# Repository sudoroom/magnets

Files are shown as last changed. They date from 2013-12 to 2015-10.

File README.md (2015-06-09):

# Sudo Magnets

These are experiments in 3D-printing fridge magnets for our hackerspace. Check it out:

* [Hack The Planet](https://github.com/sudoroom/magnets/blob/master/hack-the-planet/world.stl "'Hack The Planet' magnet")
* [Mesh The Planet](https://github.com/sudoroom/magnets/blob/master/hack-the-planet/mesh.stl "'Mesh The Planet' magnet")
* [Sudo](https://github.com/sudoroom/magnets/blob/master/sudo/sudo.stl "'Sudo' magnet")
* [Heart](https://github.com/sudoroom/magnets/blob/master/heart/heart.stl "heart magnet")
* [Double Union](https://github.com/sudoroom/magnets/blob/master/double-union/du.stl "'Double Union' magnet")
* [Anti-Surveillance](https://github.com/sudoroom/magnets/blob/master/fuck-surveillance/cube.stl "'Fuck Surveillance' magnet")
* [ABOLISH](https://github.com/sudoroom/magnets/blob/master/abolish/abolish.stl "'ABOLISH' magnet")
* [Transgender Symbol](https://github.com/sudoroom/magnets/blob/master/trans/trans.stl "'trans symbol' magnet")

## Why?

Fridge magnets are useful objects, great conversation pieces, and good advertising since people look at them every day!

## How do you print magnets??

The model has a hole for [one of these](http://www.amazon.com/gp/product/B00C786XTU/ "Is there a non-Amazon link for this?"). The printer pauses while you insert it by hand. It also moves the bed, which hopefully will make a loud distinctive noise to alert you.

## How do I make one?

Almost everything is in the `compile.sh` scripts:
* openscad command to compile an STL
* slic3r command with the exact options we use
* awk command to insert the gcode pause

Right now the scripts also do non-portable stuff like edit my PATH and fix the tempurature for our particular plastic. Sorry, I'll fix it eventually.

## What about text and images?

The world map is from Wikipedia. I prepared images and text in the Inkscape GUI. Someday I'd like to script this with Python and have entirely deterministic magnets.

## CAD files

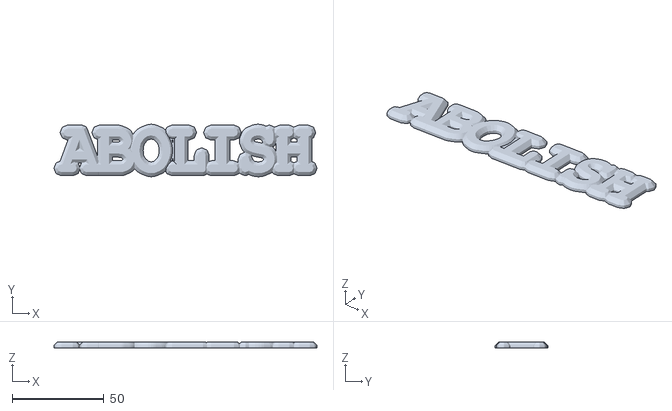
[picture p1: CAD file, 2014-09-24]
abolish/abolish-taz.stl
143.0 x 28.6 x 3.42

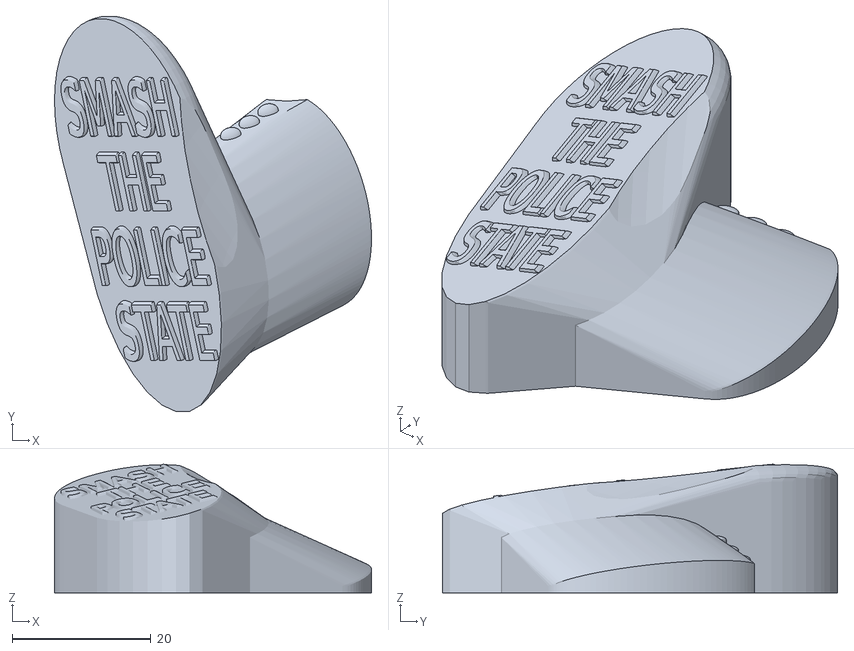
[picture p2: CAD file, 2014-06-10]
boot/boot.stl
45.7 x 57.0 x 18.6

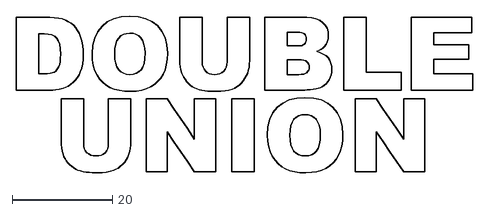
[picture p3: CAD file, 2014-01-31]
double-union/text.dxf
91.3 x 31.3

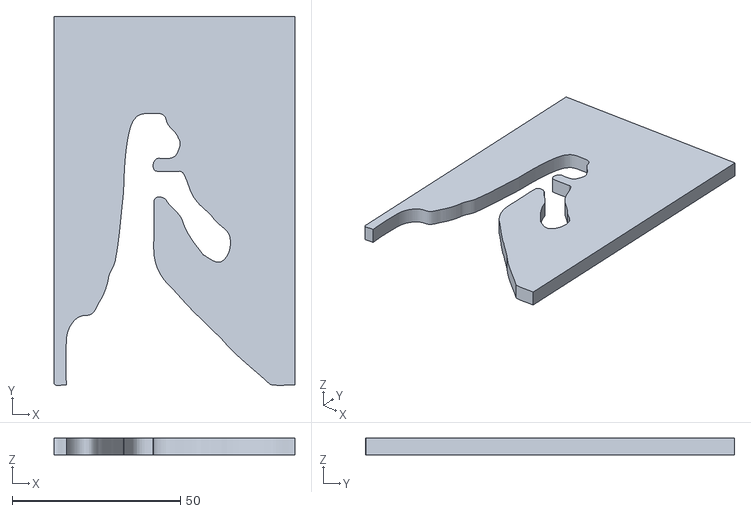
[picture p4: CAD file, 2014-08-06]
duck/duck.stl
71.6 x 109.6 x 5.00

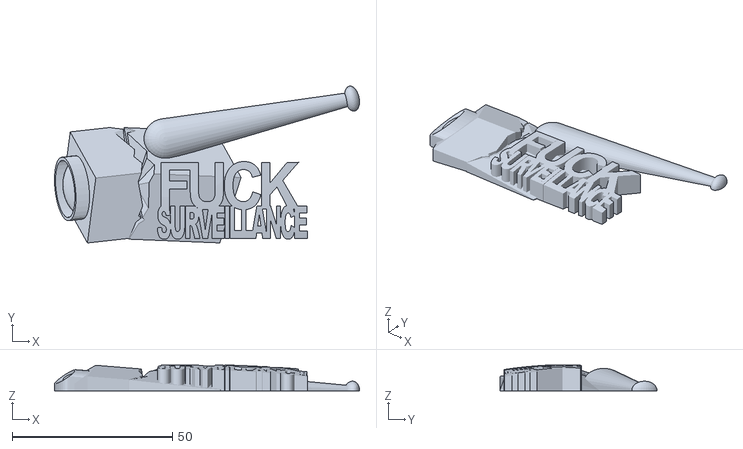
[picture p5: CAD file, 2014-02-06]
fuck-surveillance/cube.stl
95.2 x 49.0 x 8.00

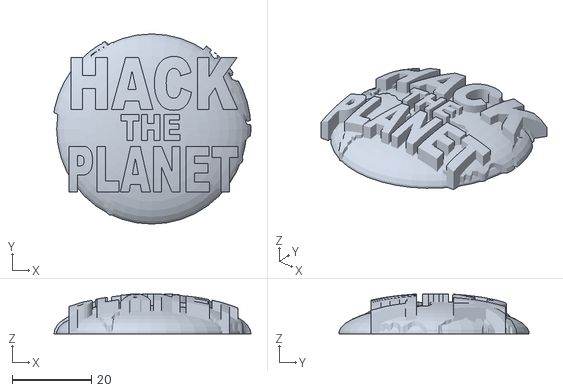
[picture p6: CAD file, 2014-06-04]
hack-the-planet/world.stl
49.6 x 47.9 x 10.0

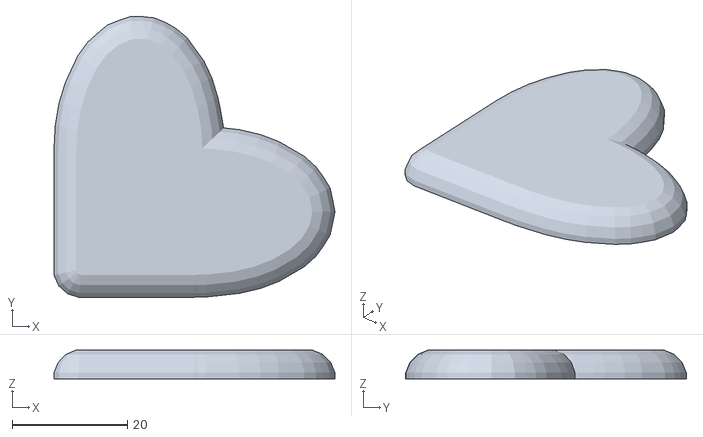
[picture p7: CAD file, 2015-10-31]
heart/heart.stl
48.7 x 48.7 x 5.00

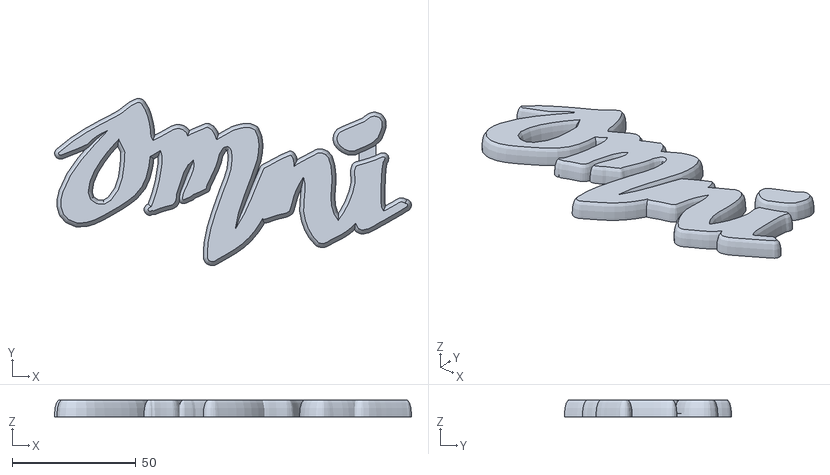
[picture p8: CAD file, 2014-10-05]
omni/omni.stl
144.4 x 67.6 x 6.85

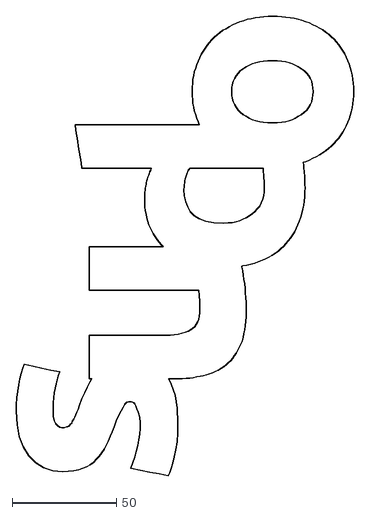
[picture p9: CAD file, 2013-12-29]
scad/sudo.dxf
162.2 x 220.8

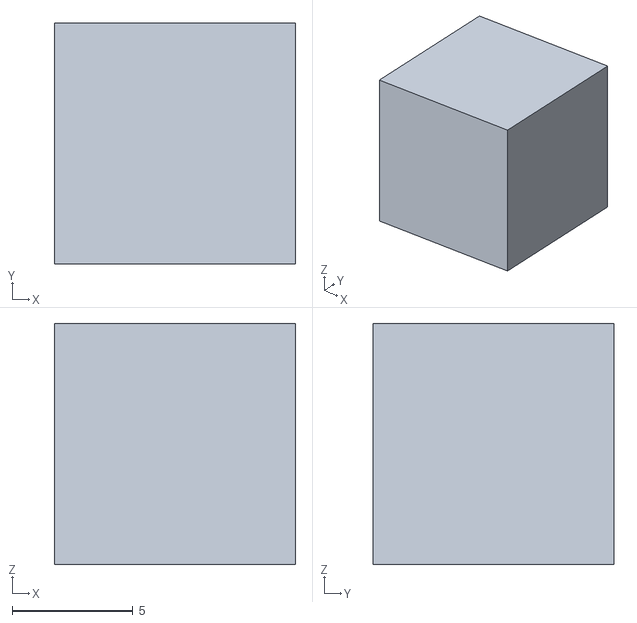
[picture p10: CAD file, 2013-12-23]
square.stl
10.0 x 10.0 x 10.0

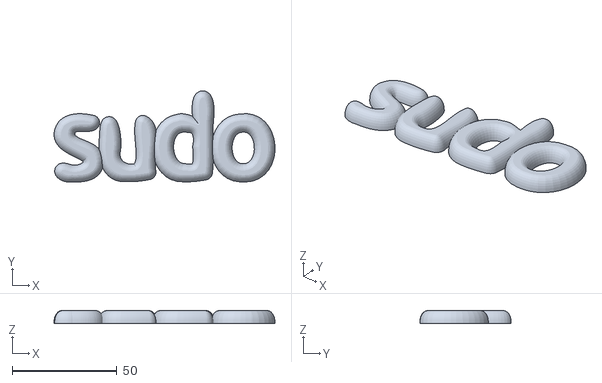
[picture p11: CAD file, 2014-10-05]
sudo/sudo.stl
105.5 x 43.6 x 5.97

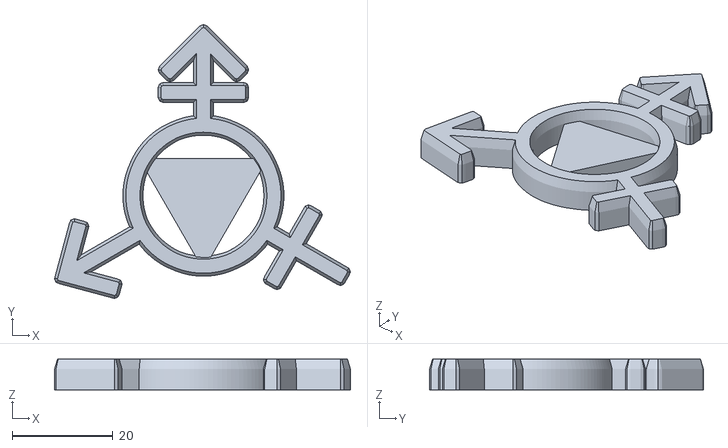
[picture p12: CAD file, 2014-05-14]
trans/trans.stl
58.8 x 54.4 x 6.10

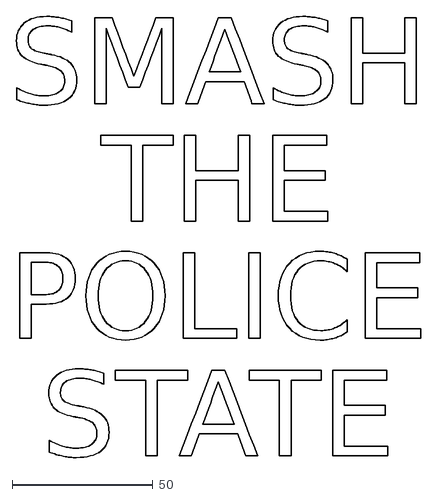
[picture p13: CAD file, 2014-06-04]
boot/smash.dxf
143.5 x 156.7

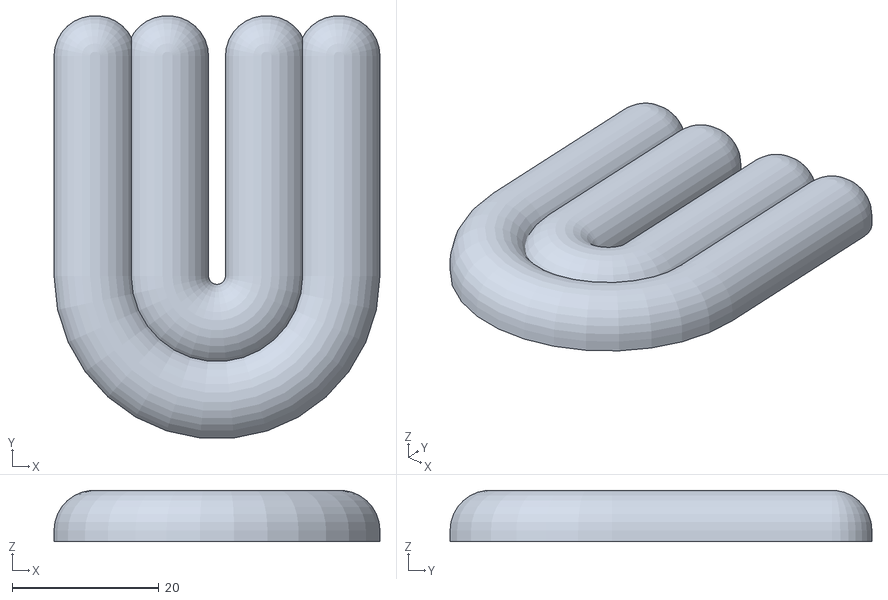
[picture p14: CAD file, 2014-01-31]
double-union/du.stl
44.5 x 57.6 x 6.97

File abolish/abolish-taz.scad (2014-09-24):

r=0.9;
s=4;

difference() {
	translate([-61.5,-11.5])
		scale([r,r,r])
		minkowski() {
			linear_extrude(height=0.1)
				import("abolish.dxf");
			difference() {
				sphere(r=s,$fn=8);
				translate([-s*3,-s*3,-s*6]) cube([s*6,s*6,s*6]);
			}
		}
	translate([0,0,0.3])  cylinder(2,7,7);
}

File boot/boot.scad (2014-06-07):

bl = 200; // boot length
inf = bl * 10;   // "infinity"
zer = 0.001; // "zero"

module ground() {
	difference() {
		minkowski() {
			translate([0,0,(zer-inf)])
				cylinder(inf,zer,zer,$fn=3);
			child();
		}
		translate([-inf/2,-inf/2,-2*inf])
			cube([inf,inf,2*inf]);
	}
}

module ankle() {
	translate([0,-45,-30])
		linear_extrude(1)
		scale([0.9,1.5]) circle(r=20,$fn=30);
}

module button() {
	scale([1,0.7,1]) sphere(r=3,$fn=40);
}

module stps() {
	translate([-18.5,-65,0])
		scale([0.26,0.55,1])
		minkowski() {
			linear_extrude(0.01)
				import("smash.dxf");
			scale([1,1,1.8]) sphere(r=1,$fn=10);
		}
}

module boot() {
	// foot
	difference() {
		hull() {
			union() {
				difference() {
					scale([1.2,2,1.1])
						sphere(r=20,$fn=50);
					translate([-50,-50,0])
						cube([100,100,100]);
				}
				translate([0,0,-1])
					linear_extrude(1)
					translate([0,-35])
					scale([1.1,2.3])
					circle(r=20);
			}
			ankle();
		}
		translate([64.5,-10,0])
			rotate([-60,0,0])
			scale([0.8,0.8,3])
			sphere(r=56,$fn=60);
	}

	// text
	stps();

	// leg
	difference() {
		hull() {
			ankle();
			translate([0,-45,-80])
				linear_extrude(1)
				scale([1.05,1.65])
				circle(r=20,$fn=100);
		}
		translate([0,-14.5,-90])
			scale([600,40,45])
			rotate([0,0,45])
			cube([1,1,1]);
	}
	translate([0,-14,-50]) button();
	translate([0,-14,-60]) button();
	translate([0,-14,-70]) button();
}

difference() {
	scale([0.5,0.5,0.18])
		translate([-10,23,0])
		ground()
		translate([0,0,85])
		rotate([20,-35,0])
		boot();

	// magnet holes
	translate([0,0,0.3])  cylinder(1.75,6.5,6.5);
	translate([0,0,-0.1]) cylinder(1.75,0.5,0.5);
}

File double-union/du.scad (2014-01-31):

tall = 30; // how tall of a U

// primitive 2D U-shape
module yoo(r) {
	union() {
		circle(r=r,$fn=30);
		translate([-r,0,0])
			square([2*r,tall]);
	}
}

// hemisphere to minkowski with
module hemisphere(r) {
	difference() {
		sphere(r=r,$fn=30);
		translate([-r,-r,-2*r]) cube([2*r,2*r,2*r]);
	}
}

// dome of a U-shape
module dome(gap, thick, pad = 0) {
	minkowski() {
		linear_extrude(height=1.5) difference() {
			yoo(r=(gap + thick - (thick/2) + 0.1));
			yoo(r=(gap + thick - (thick/2) - 0.1));
		}
		hemisphere(r=(thick/2 - pad));
	}
}

// complete single U-shape
module bar(gap,thick) {
	dome(gap=gap, thick=thick);
}

// two U-shapes together
module du(thick, gap) {
	for (i=[0,1]) {
		bar(gap=(gap + thick*i*0.9), thick=thick);
	}
}

difference() {
	translate([0,10,0]) du(thick=11, gap=1.25);

	// magnet hole
	translate([0,0,0.3])  cylinder(1.75,6.5,6.5);
	translate([0,0,-0.1]) cylinder(1.75,0.5,0.5);
}

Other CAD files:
abolish/abolish.stl
fuck-surveillance/surveillance.dxf
hack-the-planet/mesh.stl
sudo/shrunk.dxf
abolish/abolish.scad
abolish/abolish.dxf
duck/duck.dxf
duck/duck.scad
fuck-surveillance/cube.scad
fuck-surveillance/fuck.dxf
fuck-surveillance/no.dxf
fuck-surveillance/pictures.dxf
hack-the-planet/americas.dxf
hack-the-planet/hack_the_planet.dxf
hack-the-planet/mesh.scad
hack-the-planet/mesh_the_planet.dxf
hack-the-planet/world.dxf
hack-the-planet/world.scad
heart/heart.scad
omni/omni.dxf
omni/omni.scad
scad/sudo.scad
sudo/sudo.scad
tazball/sphere.scad
trans/trans.scad

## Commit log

2013-12-23 square (1 inch) - mostly just testing the unit dimensions of the tools + printer
    [square.stl]
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2013-12-23 square (250 millimeters) - this would seem to end up as the ideal size
    [square.stl]
2013-12-23 actually maybe the last one was not truly 250mm...
    [square.stl]
2013-12-23 reduce size by a factor of 1000x.... what was I doing?
    [square.stl]
2013-12-23 changed units from meters to centimeters (allegedly)
    [square.stl]
2013-12-23 changed units to millimeters?
    [square.stl]
2013-12-23 changed units to inches?
    [square.stl]
2013-12-23 changed units to feet?
    [square.stl]
2013-12-23 changed size/units to 100 millimeters
    [square.stl]
2013-12-23 changed units to centimeters
    [square.stl]
2013-12-23 turn square into shorter rectangle
    [magnet.stl]
2013-12-23 forget the block - make a cylinder with a hole - This is just a small frame around a disk-shaped magnet which we bought in a set of 50. The idea is to just snap the magnet right in! - Outer ring is 1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
    [magnet.stl]
2013-12-23 turn it into a cylinder of 15x2
    [magnet.stl]
2013-12-23 back to a cylinder with a hole - dimensions of 15-13-2-2x15-36 (not sure what that means though)
    [magnet.stl]
2013-12-23 new dimensions - outer ring: 9 - inner ring: 6.25 - height: 2, 2 (?)
    [magnet.stl]
2013-12-23 new dimensions: 8 x 6.5 x 0.5 x 2
    [magnet.stl]
2013-12-23 slightly smaller, thicker back
    [magnet.stl]
2013-12-23 thicker ring holds magnet tighter, thinner back deep enough for magnet to fit
    [magnet.stl]
2013-12-23 too small, expand everything out again, seems to work
    [magnet.stl]
2013-12-23 put a rectangle underneath - this worked, looked like a graduation cap, and the resulting magnet still lives on Sudo's fridge
    [magnet.stl]
2013-12-23 try to write 'SUDO' in jagged letters using the line tool
    [magnet.stl]
2013-12-23 a rectangle with a hole - printed UPSIDE-DOWN - the hole lives underneath and we try to work around the overhang
    [magnet.stl]
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2013-12-23 stop deleting usable things in the history, be a real repo, add a triangle shape drawn by a child in Sketchup
    [magnet.stl, sudo-jagged.stl, triangle.stl]
2013-12-23 someone drew a cat face - turns out it's really easy to just make people draw things with Sketchup's line tool, then extrude it - INSTANT NOOB MAGNET MAKER
    [kittyface.stl]
2013-12-23 prettier sudo magnet - create alpha BMP based on the style/font of sudo's logo - load that into sketchup and carefully trace along it with the line tool - this is an immensely stupid method, but work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
    [jagged.stl, traced.stl]
2013-12-23 use the BMP-tracing method for a heart magnet at the behest of a child
    [heart.stl]
2013-12-23 change heart dimensions to 6.5 1.05 1 2 (unclear what that means...)
    [heart.stl]
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2013-12-27 test slicer settings on a smaller rectangle - bumping --support-material-spacing to 5 seems noticeable. next time I should try 15...
    [rectangle.stl]
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2013-12-27 thinner edges, fix tempurature - It's not heating up all the way unless I explicitly set the tempurature - why??
2013-12-29 first stab at openscad workflow! - printing a small rectangular prism to test the positioning, scaling, etc - somewhere the positioning information gets lost, we're not sure where, good to know! - ha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
    [rectangle.scad, rectangle.stl]
2013-12-29 test openscad magnet - tiny cylinder just big enough for a magnet hole - add an extra skirt because plastic doesn't have enough time to smooth out on smaller models
    [rectangle.scad, rectangle.stl]
2013-12-29 hand-fix gcode - set tempurature properly - also try an extra wait to make sure it's really heated up
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2013-12-29 export to DXF from inkscape
    [sudo.dxf]
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2013-12-29 finally figured out how to make a file that openscad will import - i think maybe 'make all segments lines' didn't take the first time
    [sudo.dxf, sudo.scad]
2013-12-29 Sudo magnet model in SCAD
    [sudo.scad]
2013-12-29 rectangle magnet in SCAD that acually prints and the magnet fits (loosely)
    [rectangle.scad, rectangle.stl]
2013-12-29 subtract two different cylinders to make the magnet fit tighter - it sorta works
    [rectangle.scad, rectangle.stl]
2013-12-29 our first properly vector/scad-based Sudo Magnet - actually printing
    [rectangle.scad, rectangle.stl, sudo.dxf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]
2013-12-29 remove older sudo & experimental stuff
    [jagged.stl, rectangle.stl, sudo.dxf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]
2013-12-31 SUDO: wider opening for magnet, fewer skirts
    [sudo.scad, sudo.stl]
2014-01-10 start testing upside-down magnet hole again
    [mini.scad]
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2014-01-10 make things simpler until we figure out how upside-down really works
    [mini.scad, mini.stl]
2014-01-10 put a hole in the middle and sneak the magnet in
    [mini.scad, mini.stl]
2014-01-10 tiny pinhole for topological continuity - either openscad or slic3r seems to erase the internal cylinder otherwise
    [mini.scad, mini.stl]
2014-01-10 turn mini into a new heart!
    [mini.scad, mini.stl]
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2014-01-10 label heart, replace old heart
    [heart.scad, heart.stl, mini.stl]
2014-01-10 minkowski heart with sphere for smooth edges
    [heart.scad]
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2014-01-10 fix hole in the middle
    [heart.scad, heart.stl]
2014-01-10 make heart smaller - faster, less plastic
    [heart.scad, heart.stl]
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2014-01-11 much thinner heart - minkowski circle ends up being most of the height
    [heart.scad]
2014-01-11 tighter fit for the magnet
    [heart.scad, heart.stl]
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2014-01-11 dwell instead of pause? The M226 command did not end up pausing, and I missed the magnet window.
2014-01-11 less insulated magnet, try again to left before pausing
    [heart.scad]
2014-01-11 less skirts, less dense
    [heart.stl]
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2014-01-11 copy heart to world
    [world.scad]
2014-01-11 flattened sphere based on heart
    [world.scad, world.stl]
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2014-01-11 more continents - don't delete islands, etc - don't extrude them out as much
    [world.dxf, world.scad]
2014-01-11 HACK THE PLANET svg
    [hack_the_planet.dxf]
2014-01-12 overlay HACK THE PLANET on the planet
    [hack_the_planet.dxf, world.scad, world.stl]
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2014-01-13 rename mesh files to not collide with master
    [mesh.scad, mesh.stl]
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2014-01-15 sudo: revisit logo vector, experiment with curved top
    [shrunk.dxf, sudo.scad]
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2014-01-29 test shape to see how a dome works
    [test.scad]
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2014-01-31 a little shorter
    [du.scad]
2014-01-31 shorter fatter bars, overlapping
    [du.scad]
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2014-01-31 STL embedding doesn't work, just link to it
2014-01-31 remove old sketchy models - yes, this commit is snarking Google Sketchup
    [kittyface.stl, triangle.stl]
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2014-02-01 [sudo] fix the proportions - smaller hemisphere so S doesn't overlap with U - center the magnet better - tall enough to cover the magnet
    [sudo.scad]
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2014-02-01 [sudo] it doesn't need to be so tall
    [sudo.scad]
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2014-02-01 [cube] add a lens - it's a camera
    [cube.scad]
2014-02-02 [cube] automate tilt based on camera length - why should i do trig? that's what computers are for - also set the value of 'inf' based on the length
    [cube.scad]
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2014-02-02 [cube] shorter variable names
    [cube.scad]
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2014-02-05 [fuck-surveillance] crack the camera
    [cube.scad]
2014-02-05 [fuck-surveillance] variable crack depth
    [cube.scad]
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2014-02-05 [fuck-surveillance] some distance between magnet hole and crack
    [cube.scad, cube.stl]
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2014-02-05 [fuck-surveillance] new text: NO PICTURES - except very messed up
    [cube.scad, no.dxf, pictures.dxf]
2014-02-05 [fuck-surveillance] fix text
    [cube.scad, no.dxf, pictures.dxf]
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2014-02-05 [fuck surveillance] change text back to 'fuck surveillance'
    [cube.scad, fuck.dxf, surveillance.dxf]
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2014-04-06 correct magnet insertion height
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2014-05-07 [trans] fix floating artifact
    [trans.scad, trans.stl]
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2014-06-06 [boot] missing var for length of boot
    [boot.scad]
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2014-06-07 [boot] subtract sphere from side of foot
    at jake's suggestion
    [boot.scad]
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2014-10-05 [omni] more space between the legs of the M
    had to go backwards and fix the SVG topology...
    [omni.dxf]
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
